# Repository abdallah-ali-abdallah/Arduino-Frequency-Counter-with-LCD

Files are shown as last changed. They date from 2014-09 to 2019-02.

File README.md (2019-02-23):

Arduino-Frequency-Counter-with-LCD
==================================

Arduino Frequency Counter with LCD, Everything is Embedded in a single Layer PCB
with maximum frequency input up-to 64 Mhz

  Arduino Frequency Counter (up to 64 Mhz) with LCD
  
  By: Abdallah Ali Abdallah
  
  Date: Aug-2014
  
  Licence: CC-BY-NC V.4
  
  E-mail: abdallah.ali.abdallah.elmasry@gmail.com

  Note: This counter is based on chip 74xx93 (counter) used as a frequency divider by 8
  the maximum bandwidth for arduino to count is 8 Mhz and we can multiply this number 
  using 74xx93 or any other counter chip.

  the new bandwidth is determined by the counter maximum clock rate
  for example: 

  chip 74-LS-93 has (Max clock = 42 Mhz) - so you can measure up to 42 Mhz
  
  chip 74-HC-93 has (Max clock = 64 Mhz) - so you can measure up to 64 Mhz
  
  Note: Minmum input voltage is 2 volt
		    Maximum input voltage is 5.1 volt
		
=============================================	

  This project Based on counter Library by:  
  
  Martin Nawrath KHM LAB3
  Kunsthochschule f¸r Medien Kˆln
  Academy of Media Arts
  http://www.khm.de
  http://interface.khm.de/index.php/labor/experimente/

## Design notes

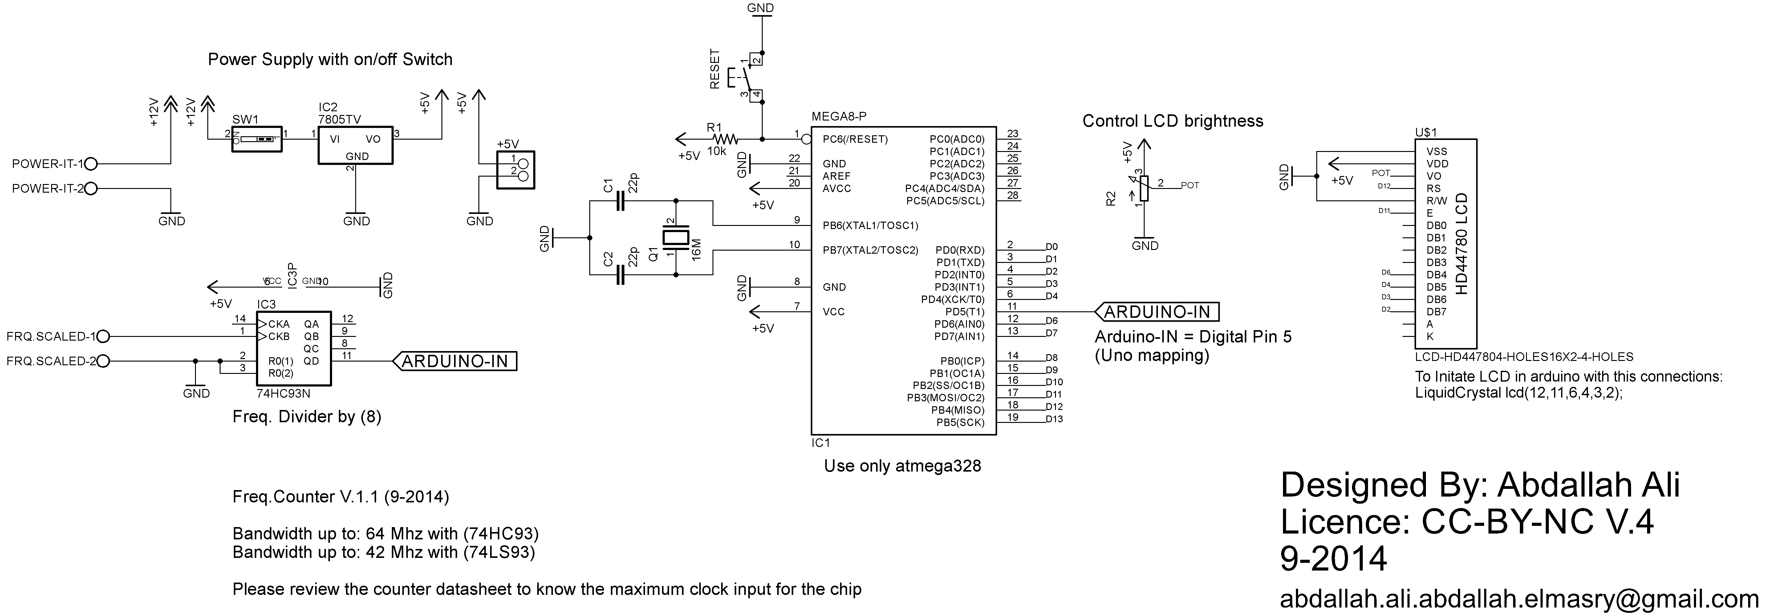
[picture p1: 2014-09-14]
Schematics.png

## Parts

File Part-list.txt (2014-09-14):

Partlist

Exported from Freq.Counter.V.1.0.sch at 13/09/2014 08:43:06 ã

EAGLE Version 6.3.0 Copyright (c) 1988-2012 CadSoft

Assembly variant: 

Part       Value                          Device                         Package         Library                      Sheet

+5V                                       PINHD-1X2                      1X02            pinhead                      1
C1         22p                            C-EU025-025X050                C025-025X050    rcl                          1
C2         22p                            C-EU025-025X050                C025-025X050    rcl                          1
FRQ.SCALED                                W237-102                       W237-102        con-wago-500                 1
IC1        MEGA8-P                        MEGA8-P                        DIL28-3         atmel                        1
IC2        7805TV                         7805TV                         TO220V          linear                       1
IC3        74HC93N                        74HC93N                        DIL14           74xx-eu                      1
POWER-IT                                  W237-102                       W237-102        con-wago-500                 1
Q1         16M                            XTAL/S                         QS              special                      1
R1         10k                            R-US_0207/10                   0207/10         rcl                          1
R2                                        3RP/1610N                      3RP/1610N       pot                          1
RESET                                     10-XX                          B3F-10XX        switch-omron                 1
SW1                                       SW_DIP-1                       EDG-01          special                      1
U$1        LCD-HD447804-HOLES16X2-4-HOLES LCD-HD447804-HOLES16X2-4-HOLES LCD-16X2-4HOLES LCD-Library-EagleCAD-HD44780 1

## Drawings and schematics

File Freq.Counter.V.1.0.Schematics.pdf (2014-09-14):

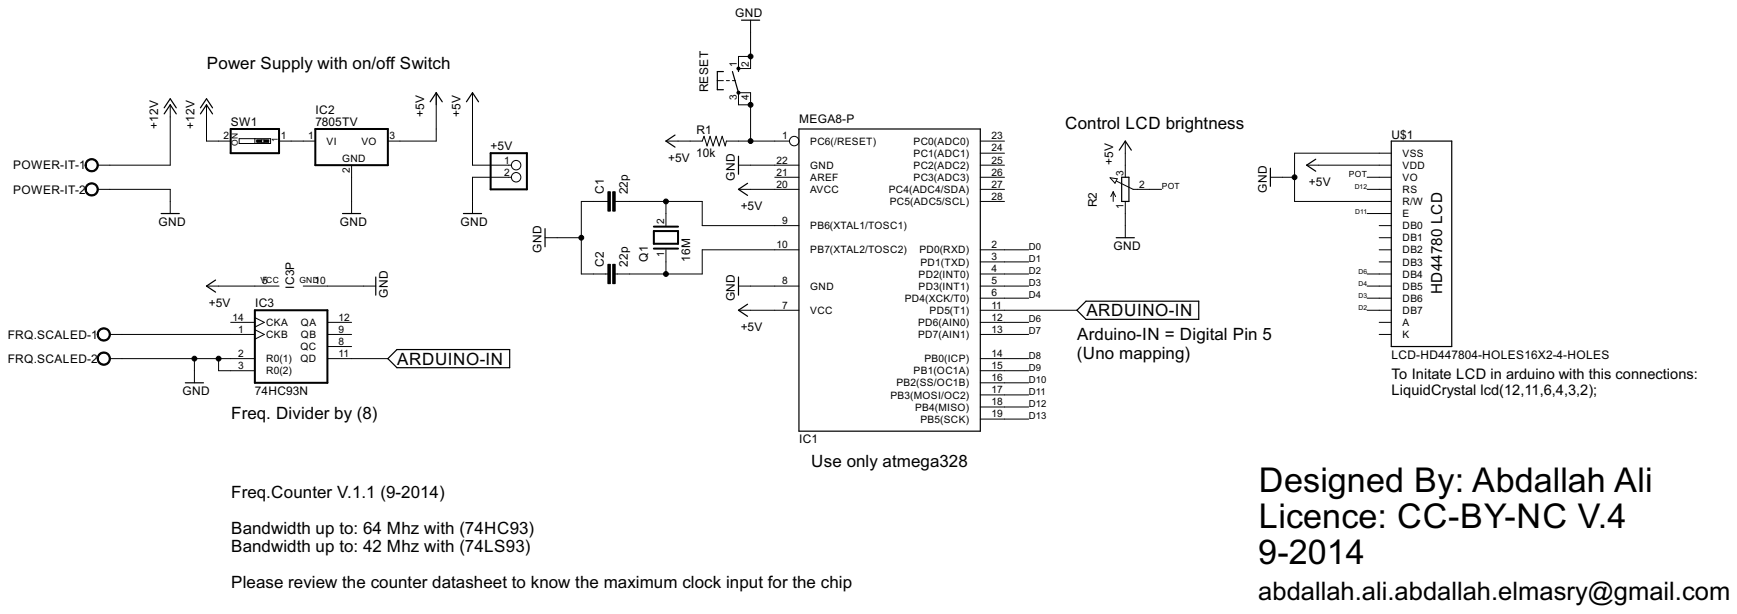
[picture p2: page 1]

Power Supply with on/off Switch

ARDUINO-IN
Arduino-IN = Digital Pin 5
(Uno mapping)

LCD-HD447804-HOLES16X2-4-HOLES
To Initate LCD in arduino with this connections:
LiquidCrystal lcd(12,11,6,4,3,2);

Designed By: Abdallah Ali
Licence: CC-BY-NC V.4
abdallah.ali.abdallah.elmasry@gmail.com

Bandwidth up to: 64 Mhz with (74HC93)
Bandwidth up to: 42 Mhz with (74LS93)

Please review the counter datasheet to know the maximum clock input for the chip

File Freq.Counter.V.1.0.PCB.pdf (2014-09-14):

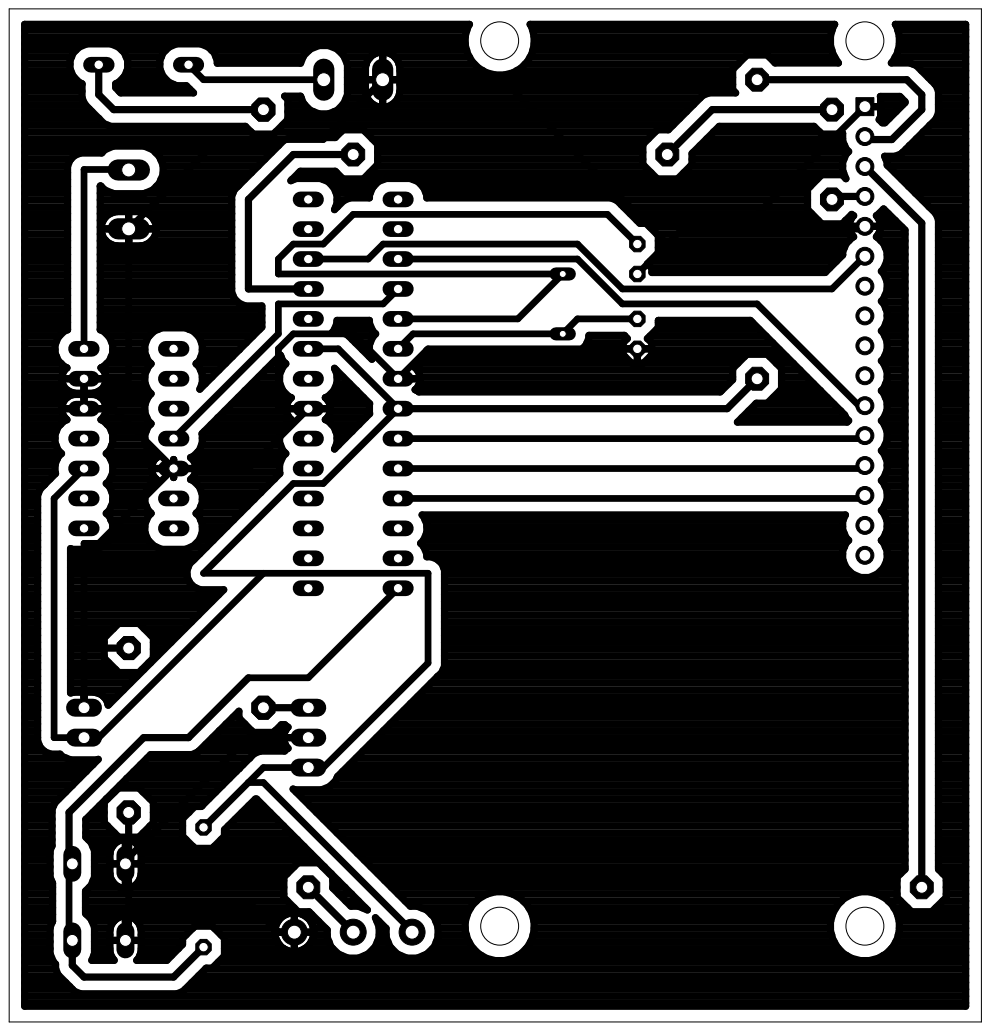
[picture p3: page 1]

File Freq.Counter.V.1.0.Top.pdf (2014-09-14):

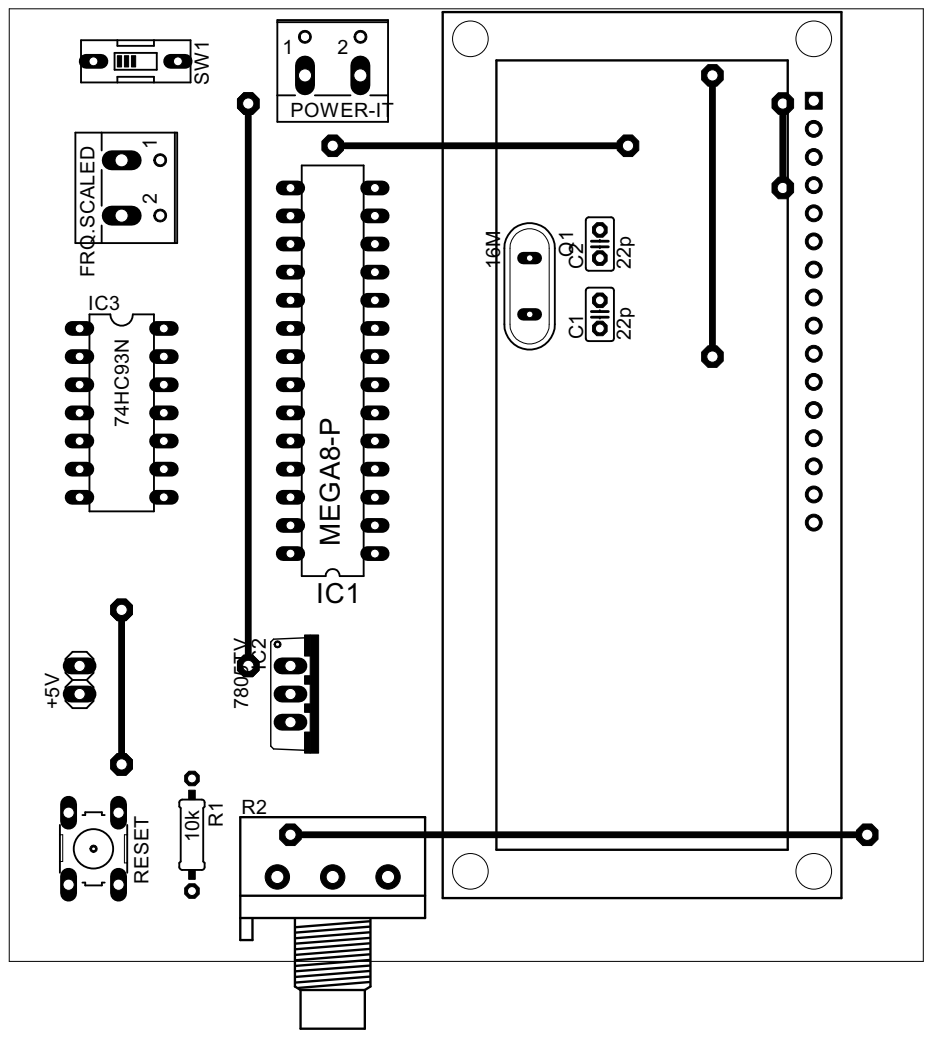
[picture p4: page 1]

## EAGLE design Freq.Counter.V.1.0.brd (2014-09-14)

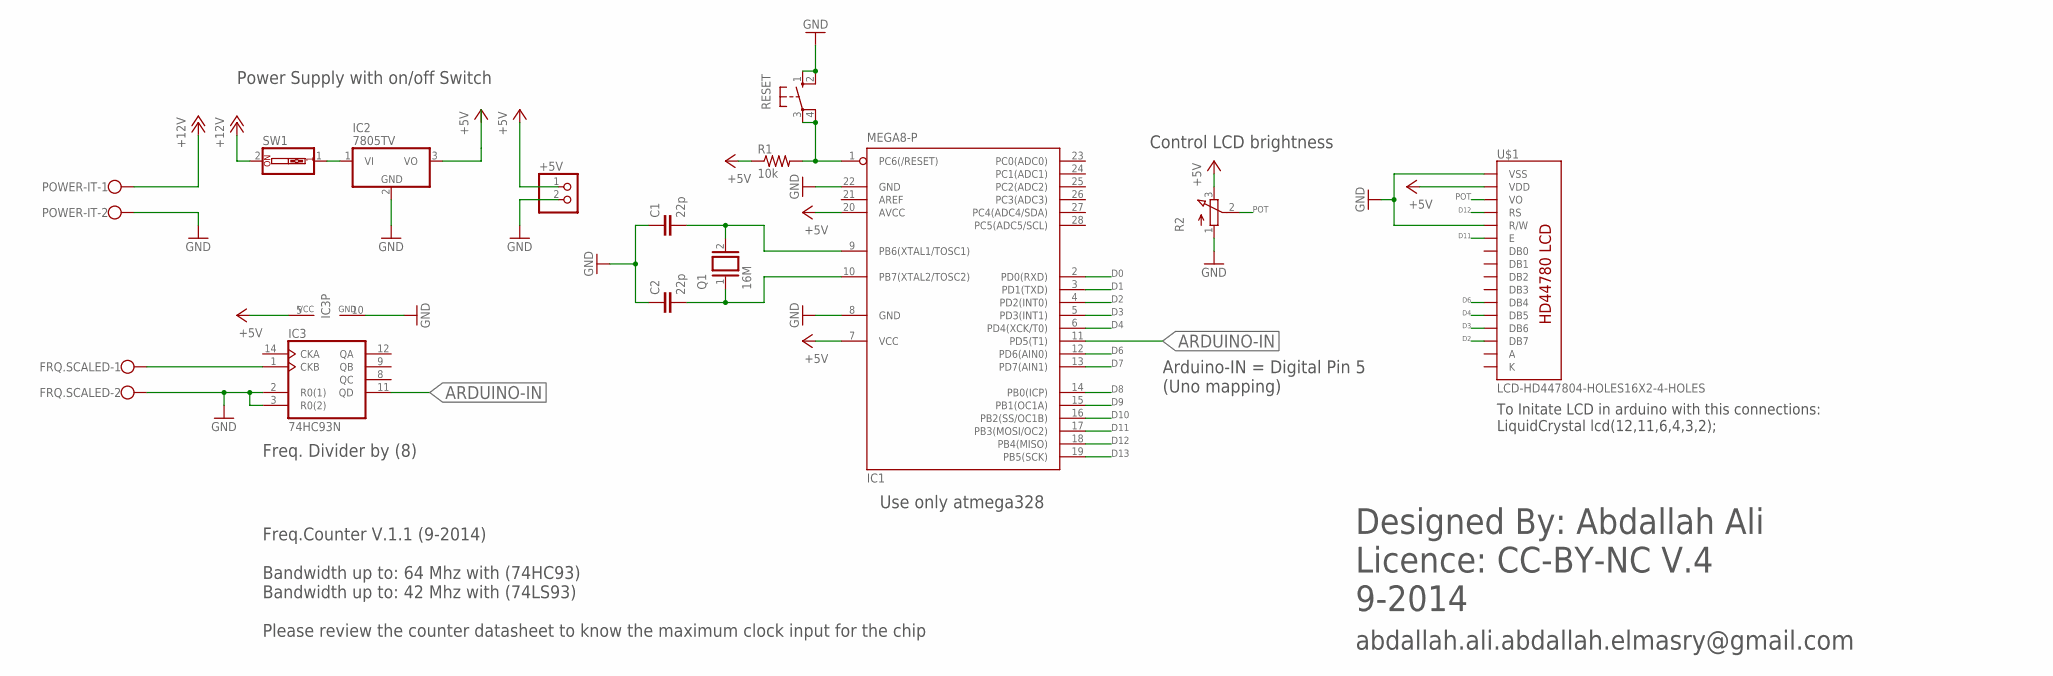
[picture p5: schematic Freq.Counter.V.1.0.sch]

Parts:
+5V: PINHD-1X2; 1X02
C1, C2: 22p; C025-025X050
FRQ.SCALED: W237-102
IC1: MEGA8-P; DIL28-3
IC2: 7805TV; TO220V
IC3: 74HC93N; DIL14
POWER-IT: W237-102
Q1: 16M; QS
R1: 10k; 0207/10
R2: 3RP/1610N
RESET: 10-XX; B3F-10XX
SW1: SW_DIP-1; EDG-01
U$1: LCD-HD447804-HOLES16X2-4-HOLES; LCD-16X2-4HOLES

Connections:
+5V: +5V.1, IC1.7 (VCC), IC1.20 (AVCC), IC2.3 (VO), IC3.5 (VCC), R1.1, R2.3 (E), U$1.2 (VDD)
+12V: POWER-IT.1, SW1.2
A: U$1.15 (A)
ARDUINO-IN: IC1.11 (PD5(T1)), IC3.11 (QD)
D0: IC1.2 (PD0(RXD))
D1: IC1.3 (PD1(TXD))
D2: IC1.4 (PD2(INT0)), U$1.14 (DB7)
D3: IC1.5 (PD3(INT1)), U$1.13 (DB6)
D4: IC1.6 (PD4(XCK/T0)), U$1.12 (DB5)
D6: IC1.12 (PD6(AIN0)), U$1.11 (DB4)
D7: IC1.13 (PD7(AIN1))
D8: IC1.14 (PB0(ICP))
D9: IC1.15 (PB1(OC1A))
D10: IC1.16 (PB2(SS/OC1B))
D11: IC1.17 (PB3(MOSI/OC2)), U$1.6 (E)
D12: IC1.18 (PB4(MISO)), U$1.4 (RS)
D13: IC1.19 (PB5(SCK))
GND: +5V.2, C1.1, C2.1, FRQ.SCALED.2, IC1.8 (GND), IC1.22 (GND), IC2.2 (GND), IC3.2 (R0(1)), IC3.3 (R0(2)), IC3.10 (GND), POWER-IT.2, R2.1 (A), RESET.1 (S), RESET.2 (S1), U$1.1 (VSS), U$1.5 (R/W)
K: U$1.16 (K)
unnamed: IC1.1 (PC6(/RESET)), R1.2, RESET.3, RESET.4 (P1)
unnamed: IC2.1 (VI), SW1.1
unnamed: FRQ.SCALED.1, IC3.1 (CKB)
unnamed: C1.2, IC1.9 (PB6(XTAL1/TOSC1)), Q1.2
unnamed: C2.2, IC1.10 (PB7(XTAL2/TOSC2)), Q1.1
POT: R2.2 (S), U$1.3 (VO)

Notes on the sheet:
To Initate LCD in arduino with this connections: LiquidCrystal lcd(12,11,6,4,3,2);
Freq.Counter V.1.1 (9-2014) Bandwidth up to: 64 Mhz with (74HC93) Bandwidth up to: 42 Mhz with (74LS93) Please review the counter datasheet to know the maximum clock input for the chip
Use only atmega328
Power Supply with on/off Switch
Freq. Divider by (8)
Arduino-IN = Digital Pin 5 (Uno mapping)
Control LCD brightness
Designed By: Abdallah Ali Licence: CC-BY-NC V.4 9-2014
abdallah.ali.abdallah.elmasry@gmail.com

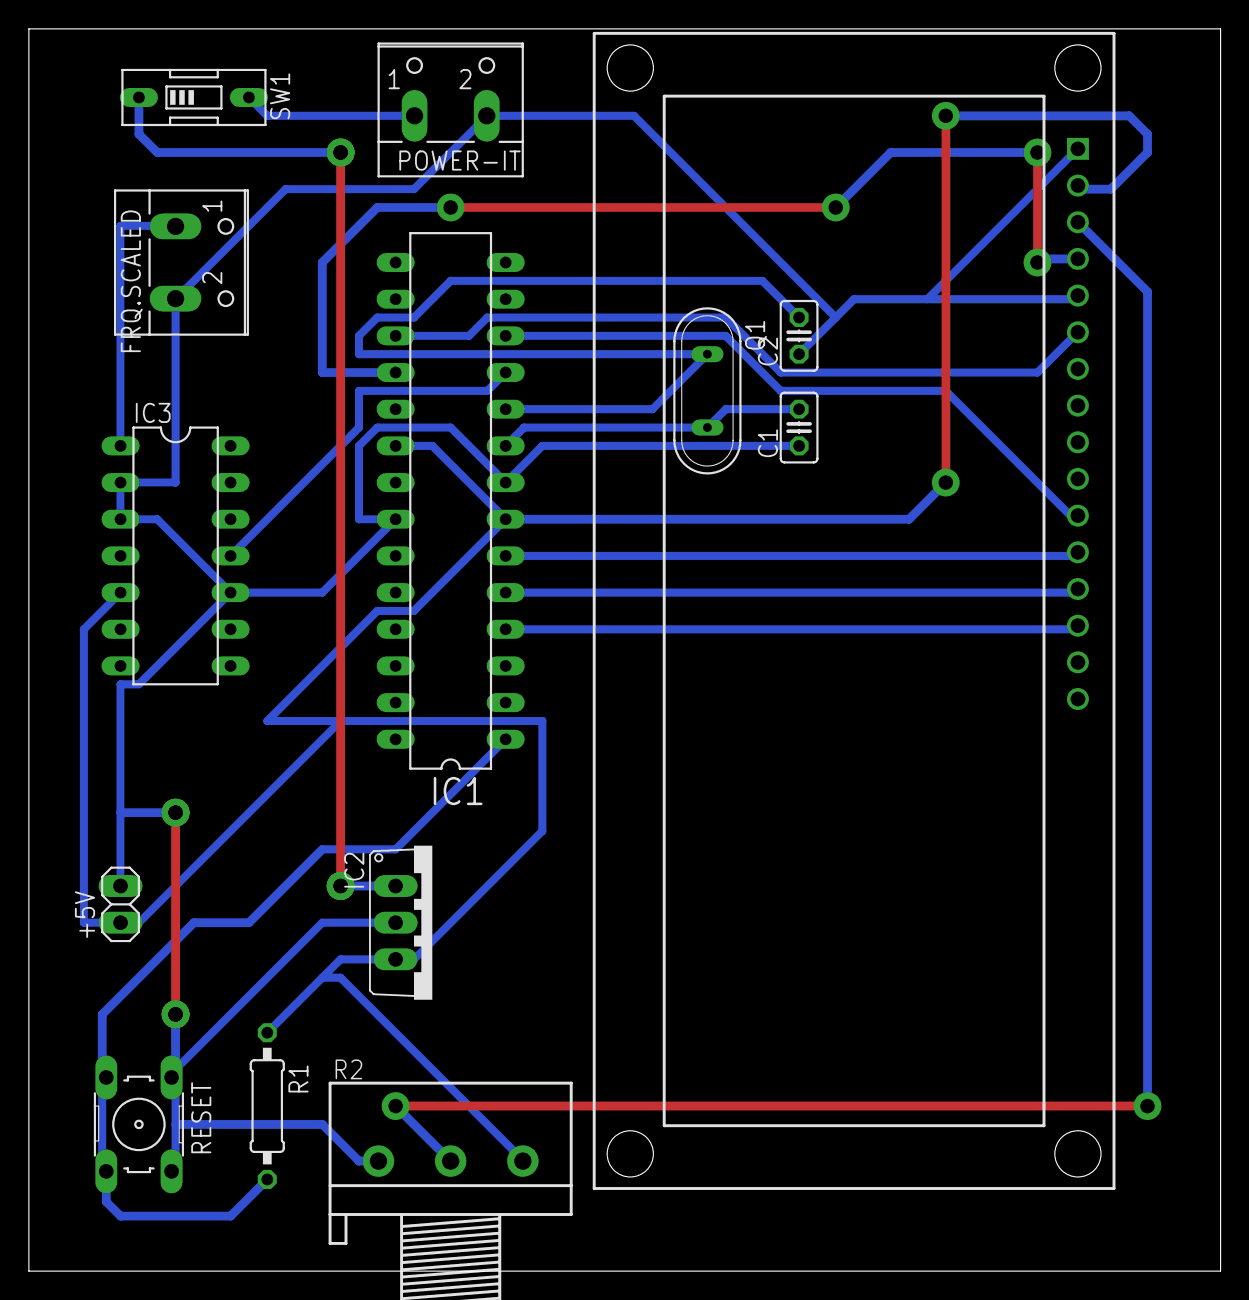
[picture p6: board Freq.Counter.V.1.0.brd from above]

Board: 2 copper layers, 82.5 x 86.0 mm, 14 parts (0 on the bottom side), 16 nets.

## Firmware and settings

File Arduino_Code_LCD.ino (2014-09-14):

/*
  Arduino Frequency Counter (up to 64 Mhz) with LCD
  By: Abdallah Ali 
  Date: Aug-2014
  Licence: CC-BY-NC V.4

  
  Note: This counter use chip 74xx93 (counter) as a frequency divider by 8
  the maximum bandwidth for arduino is 8 Mhz and we can multiply this number
  the new maximum rate is determined by the counter maximum clock rate
  for example: 
  
  chip 74-LS-93 has (Max clock = 42 Mhz) - so you can measure up to 42 Mhz
  chip 74-HC-93 has (Max clock = 64 Mhz) - so you can measure up to 64 Mhz
  
  Note: Minmum input voltage is 2 volt
		Maximum input voltage is 5.1 volt
		
  This project Based on counter Library by:  
  
  Martin Nawrath KHM LAB3
  Kunsthochschule f¸r Medien Kˆln
  Academy of Media Arts
  http://www.khm.de
  http://interface.khm.de/index.php/labor/experimente/	
 */
 
 
#include <FreqCounter.h>

// include the library code:
#include <LiquidCrystal.h>

// initialize the library with the numbers of the interface pins
LiquidCrystal lcd(12, 11, 6, 4, 3, 2);
// pin number was designed for the PCB

unsigned long frq;
int cnt;


void setup() 
{
  lcd.begin(16, 2);
}


void loop() {


  // wait if any serial is going on
  FreqCounter::f_comp=10;   // Cal Value / Calibrate with professional Freq Counter
  FreqCounter::start(1000);  // values to control resoulation, where  10, 100 or 1000 ms are practicable for a resolution of 100, 10 and 1 Hz 

  while (FreqCounter::f_ready == 0) 

  frq=FreqCounter::f_freq;

  lcd.setCursor(0, 0);
  lcd.print("Frequency(Hz):");
  lcd.setCursor(4, 1);
  lcd.print(frq*8);   
  delay(100);

}  

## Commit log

2014-08-29 Sketch to use the counter with the PCB+LCD
2014-08-29 The PCB File as PDF
2014-08-29 The PCB File as EagleCAD Source
    [Freq.Counter.V.1.0.brd]
2014-08-29 The Schematics File as EagleCAD Source
    [Freq.Counter.V.1.0.sch]
2014-08-29 The Schematics File, PDF Version
2014-08-29 Schematics, PNG version
2014-08-29 How to build the device
2014-08-29 Top View of the PCB
2014-09-14 Arduino Freq. Counter (up to 64 Mhz) V.1.1
    Arduino Freq. Counter (up to 64 Mhz) V.1.1
    With smaller PCB
    [Freq.Counter.V.1.0.brd, Freq.Counter.V.1.0.sch]
